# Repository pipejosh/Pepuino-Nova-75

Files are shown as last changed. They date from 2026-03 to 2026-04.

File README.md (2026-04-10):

## Introducing the pepuino75

This is the pepuino75, a 75 percent keyboard, featuring my custom microcontroler, the pepuinoNanoV1 (https://github.com/pipejosh/pepuinoNano-devBoard) althought it is also compatible with a raspberry pi pico!. This keyboard also features a rotary encoder, design to make it as compact as possible, without lossing any of its features!

### Keyboard!

(With 3d printed display)

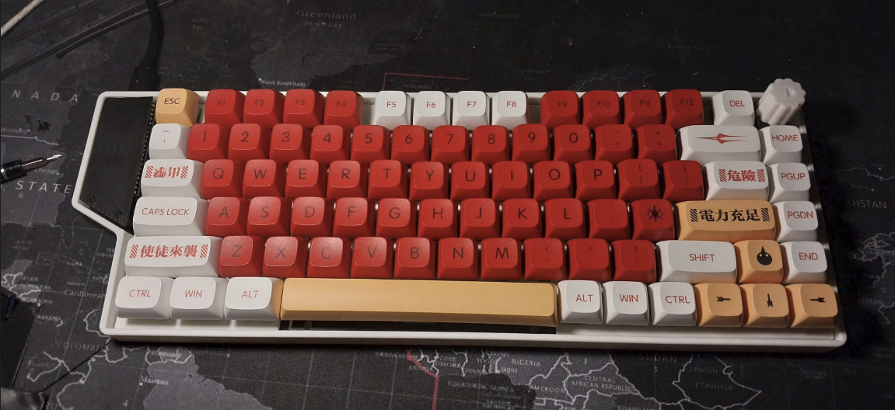
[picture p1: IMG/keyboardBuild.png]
build


(With acrylic display)

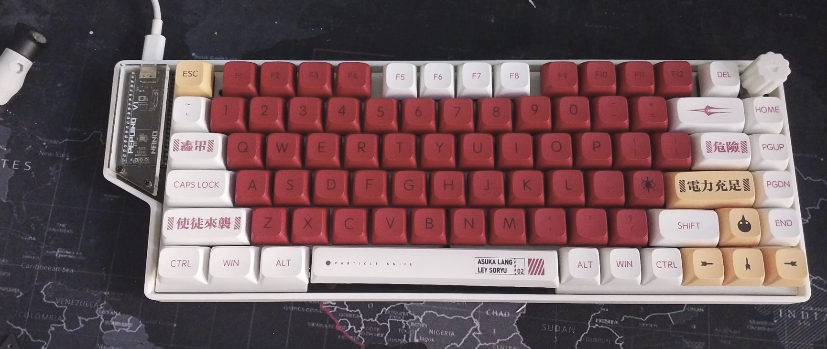
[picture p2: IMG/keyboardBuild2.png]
build


### RENDER
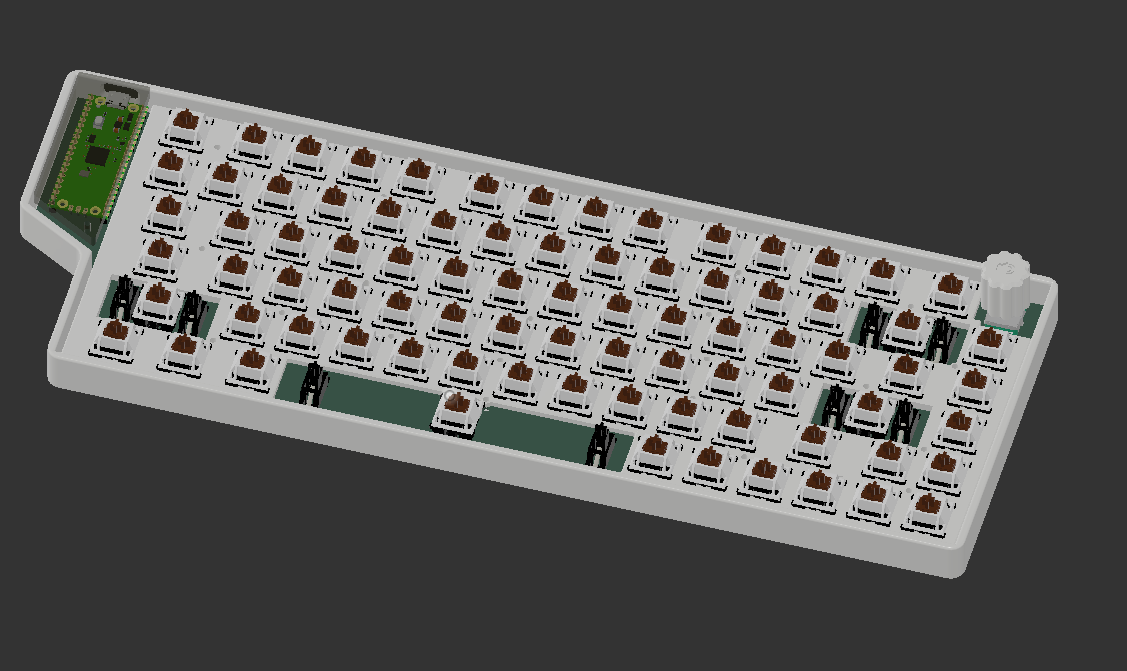
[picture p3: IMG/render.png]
 

### SCHEMATIC
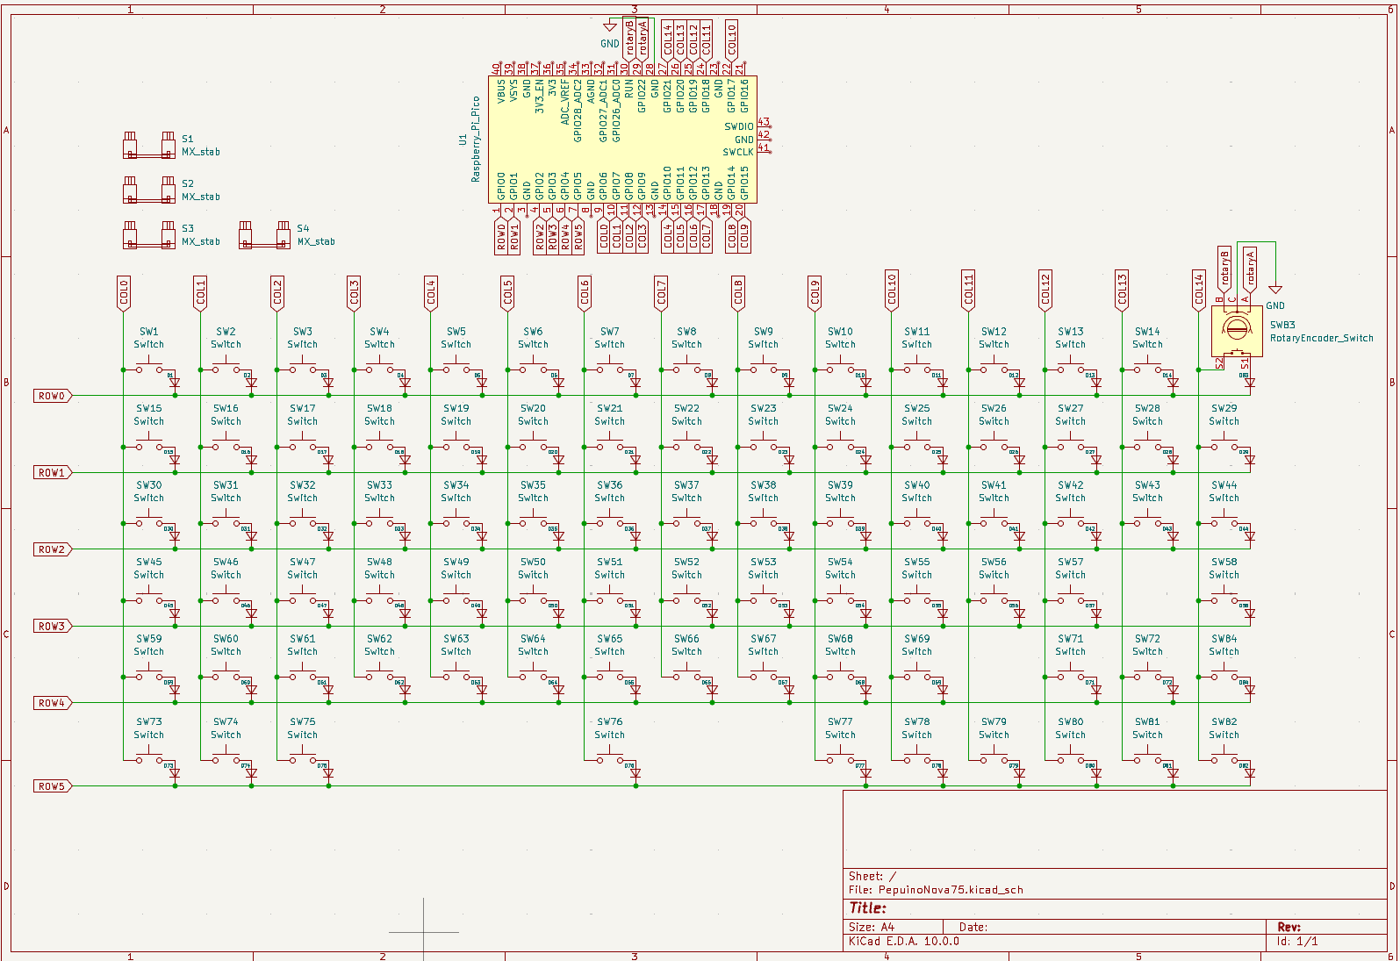
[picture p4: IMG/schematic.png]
schematic
 

### PCB
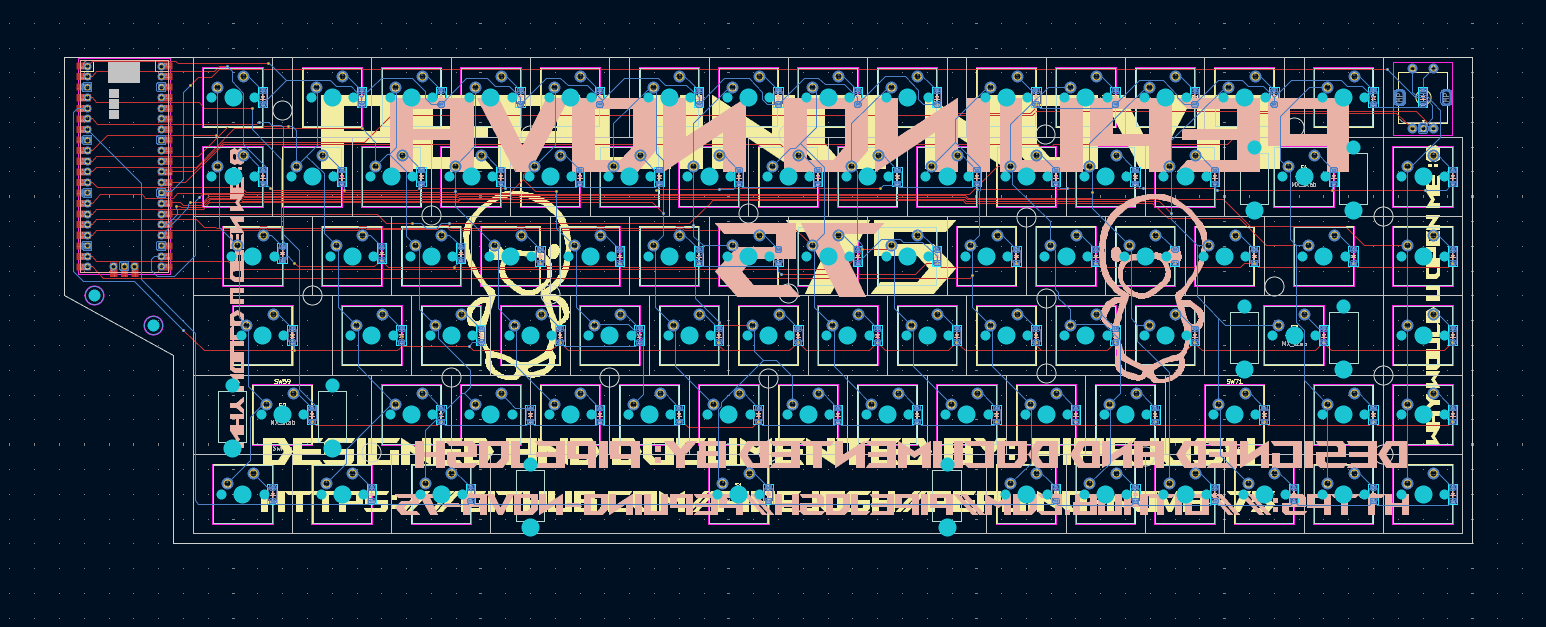
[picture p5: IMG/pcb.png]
 
### CASE
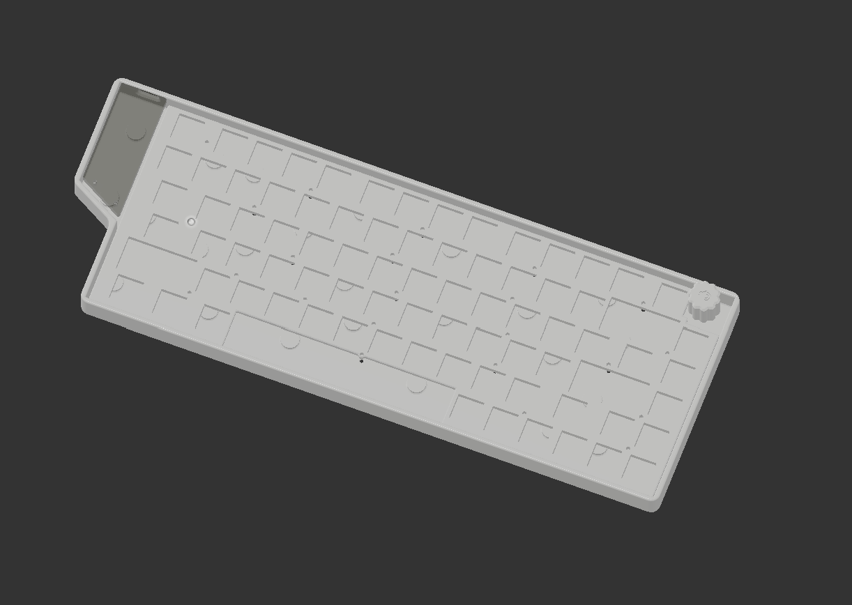
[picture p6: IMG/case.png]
case
 

### BOM
BOM 

### Firmware

This keyboard uses kmk feel free to use the official (https://github.com/KMKfw/kmk_firmware/blob/main/docs/en/Getting_Started.md) documentation in order to flash and install kmk in you microcontroller the firmware folder has the code.py which is what you should copy and paste into your board 

## KIT Components

| Item | Description | Quantity | Unit Price | Total Price | URL |
|---|---|---:|---:|---:|---|
| Keycaps Set | Keycaps for the keyboard | 126 | 0.07 | 8.31 | https://www.aliexpress.com/item/1005007321700850.html |
| Switches | Mechanical switches | 90 | 0.20 | 18.11 | https://www.aliexpress.com/item/1005009787231480.html |
| Diodes | SMD diodes | 100 | 0.03 | 3.15 | https://www.aliexpress.com/item/1005007160563285.html |
| USB-C Cable | USB-C cable | 1 | 3.31 | 3.31 | https://www.aliexpress.com/item/1005005080440661.html |
| M2 Standoff | M2 standoff 5 mm | 50 | 0.05 | 2.50 | https://www.aliexpress.com/item/1005006049595637.html |
| M2 Screw | M2 screw 5 mm | 50 | 0.03 | 1.60 | https://www.aliexpress.com/item/1005005070119421.html |
| Stabilizers | MX stabilizers (6.25u & 2u) | 5 | 0.73 | 3.64 | https://www.aliexpress.com/item/1005007212869086.html |
| Taxes | AliExpress tax | — | — | 4.28 | — |

**KIT Components Subtotal:** 44.90

---

## PCB Costs

| Item | Description | Cost |
|---|---|---:|
| JLCPCB | Pepuino75 PCB | 26.47 |
| JLCPCB Shipping | PCB shipping + taxes | 21.58 |

**PCB Subtotal:** 48.05

---

## GRAND TOTAL

| Category | Amount |
|---|---:|
| KIT Components | 44.90 |
| PCB | 48.05 |
| **TOTAL** | **92.95** |

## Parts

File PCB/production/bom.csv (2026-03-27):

Designator | Footprint | Quantity | Value | LCSC Part #
D1, D10, D11, D12, D13, D14, D15, D16, D17, D18, D19, D2, D20, D21, D22, D23, D24, D25, D26, D27, D28, D29, D3, D30, D31, D32, D33, D34, D35, D36, D37, D38, D39, D4, D40, D41, D42, D43, D44, D45, D46, D47, D48, D49, D5, D50, D51, D52, D53, D54, D55, D56, D57, D58, D59, D6, D60, D61, D62, D63, D64, D65, D66, D67, D68, D69, D7, D71, D72, D73, D74, D75, D76, D77, D78, D79, D8, D80, D81, D82, D83, D84, D9 | Diode_SOD-123 | 83 | ~
S1 | Stabilizer_MX_6.25u | 1 | MX_stab
S2, S3, S4, S5 | Stabilizer_MX_2.00u | 4 | MX_stab
SW1, SW10, SW11, SW12, SW13, SW14, SW15, SW16, SW17, SW18, SW19, SW2, SW20, SW21, SW22, SW23, SW24, SW25, SW26, SW27, SW29, SW3, SW31, SW32, SW33, SW34, SW35, SW36, SW37, SW38, SW39, SW4, SW40, SW41, SW42, SW44, SW46, SW47, SW48, SW49, SW5, SW50, SW51, SW52, SW53, SW54, SW55, SW56, SW58, SW6, SW60, SW61, SW62, SW63, SW64, SW65, SW66, SW67, SW68, SW69, SW7, SW72, SW77, SW78, SW79, SW8, SW80, SW81, SW82, SW84, SW9 | MX_PCB_1.00u | 71 | Switch
SW28 | MX_PCB_2.00u | 1 | Switch
SW30, SW43 | MX_PCB_1.50u | 2 | Switch
SW45, SW71 | MX_PCB_1.75u | 2 | Switch
SW57, SW59 | MX_PCB_2.25u | 2 | Switch
SW73, SW74, SW75 | MX_PCB_1.25u | 3 | Switch
SW76 | MX_PCB_6.25u | 1 | Switch
SW83 | ROT_Alps_EC11E-Switch | 1 | RotaryEncoder_Switch
U1 | Raspberry_Pi_Pico | 1 | Raspberry_Pi_Pico

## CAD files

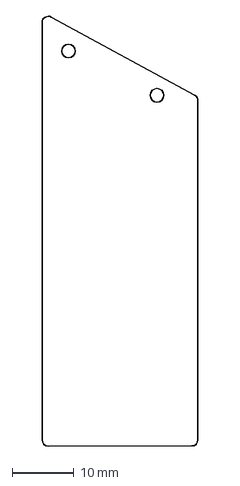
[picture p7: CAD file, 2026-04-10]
CAD/pepuinoNova75Acrylic.dxf
25.2 x 69.5 mm

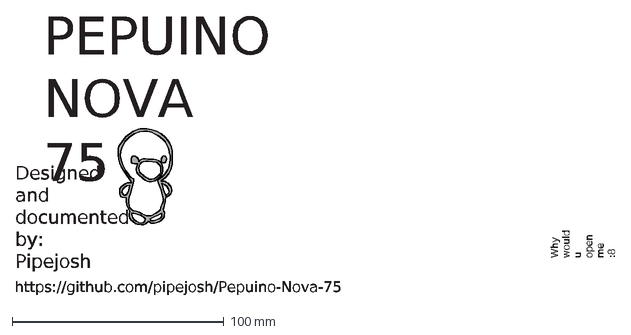
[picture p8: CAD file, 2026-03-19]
PCB/IMG/silkscreenBack.dxf
PEPUINO NOVA
75
Why would u open me :8
Designed and documented by: Pipejosh
https://github.com/pipejosh/Pepuino-Nova-75

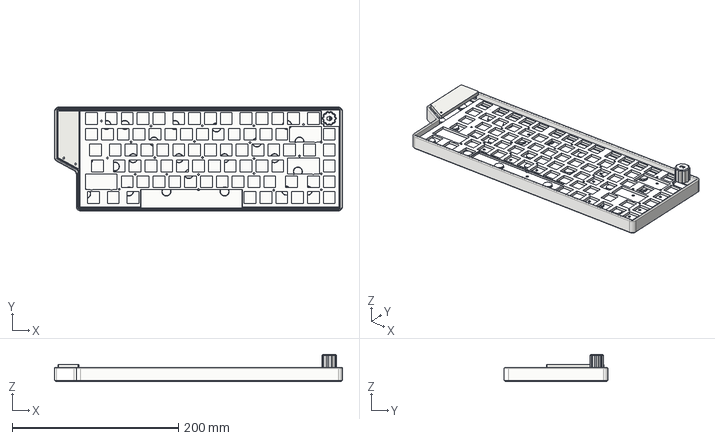
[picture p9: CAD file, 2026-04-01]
CAD/pepuino75CaseSwitchplateEncoder.step
346.1 x 124.7 x 32.6 mm

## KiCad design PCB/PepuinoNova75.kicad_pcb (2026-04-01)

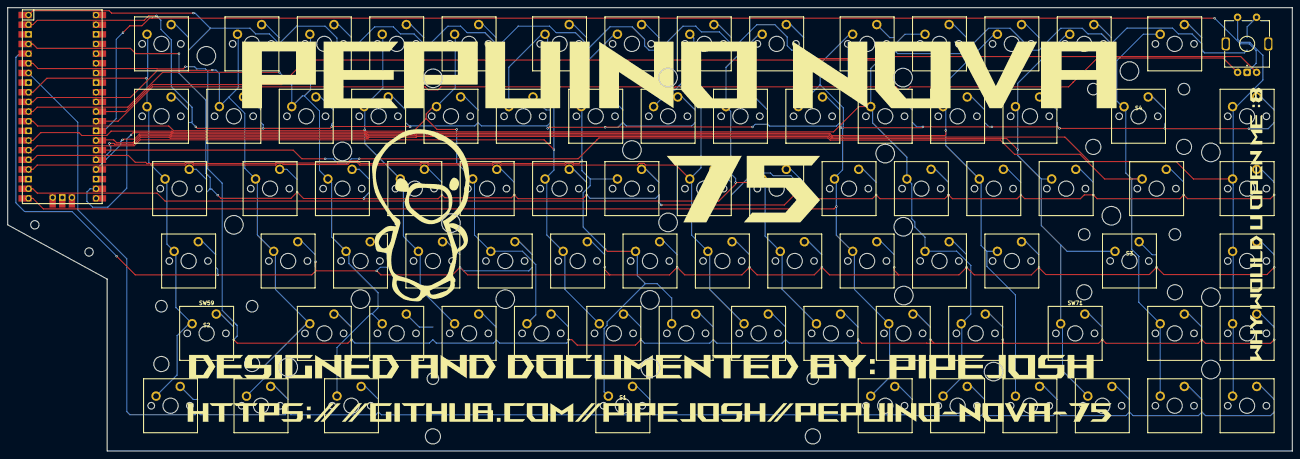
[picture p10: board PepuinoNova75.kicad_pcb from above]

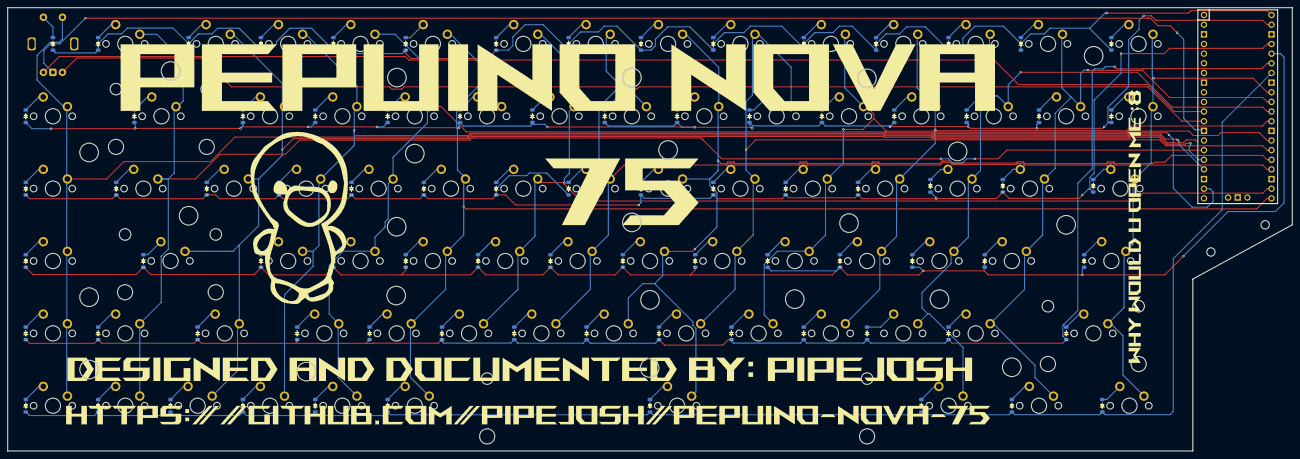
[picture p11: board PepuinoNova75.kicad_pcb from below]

Board: 2 copper layers, 338.1 x 116.7 mm, 173 parts (83 on the bottom side), 107 nets.

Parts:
D1, D2, D3, D4, D5, D6, D7, D8, D9, D10, D11, D12, D13, D14, D15, D16, D17, D18, D19, D20, D21, D22, D23, D24, D25, D26, D27, D28, D29, D30, D31, D32, D33, D34, D35, D36, D37, D38, D39, D40, D41, D42, D43, D44, D45, D46, D47, D48, D49, D50, D51, D52, D53, D54, D55, D56, D57, D58, D59, D60, D61, D62, D63, D64, D65, D66, D67, D68, D69, D71, D72, D73, D74, D75, D76, D77, D78, D79, D80, D81, D82, D83, D84: Diode_SOD-123
H16, H21: MountingHole; MountingHole_2.2mm_M2
S1: MX_stab; Stabilizer_MX_6.25u
S2, S3, S4: MX_stab; Stabilizer_MX_2.00u
SW1, SW2, SW3, SW4, SW5, SW6, SW7, SW8, SW9, SW10, SW11, SW12, SW13, SW14, SW15, SW16, SW17, SW18, SW19, SW20, SW21, SW22, SW23, SW24, SW25, SW26, SW27, SW29, SW31, SW32, SW33, SW34, SW35, SW36, SW37, SW38, SW39, SW40, SW41, SW42, SW44, SW46, SW47, SW48, SW49, SW50, SW51, SW52, SW53, SW54, SW55, SW56, SW58, SW60, SW61, SW62, SW63, SW64, SW65, SW66, SW67, SW68, SW69, SW72, SW77, SW78, SW79, SW80, SW81, SW82, SW84: Switch; MX_PCB_1.00u
SW28: Switch; MX_PCB_2.00u
SW30, SW43: Switch; MX_PCB_1.50u
SW45, SW71: Switch; MX_PCB_1.75u
SW57, SW59: Switch; MX_PCB_2.25u
SW73, SW74, SW75: Switch; MX_PCB_1.25u
SW76: Switch; MX_PCB_6.25u
SW83: RotaryEncoder_Switch; ROT_Alps_EC11E-Switch
U1: Raspberry_Pi_Pico

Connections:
COL0: SW1.1, SW15.1, SW30.1, SW45.1, SW59.1, SW73.1, U1.9 (GPIO6)
COL1: SW2.1, SW16.1, SW31.1, SW46.1, SW60.1, SW74.1, U1.10 (GPIO7)
COL2: SW3.1, SW17.1, SW32.1, SW47.1, SW61.1, SW75.1, U1.11 (GPIO8)
COL3: SW4.1, SW18.1, SW33.1, SW48.1, SW62.1, U1.12 (GPIO9)
COL4: SW5.1, SW19.1, SW34.1, SW49.1, SW63.1, U1.14 (GPIO10)
COL5: SW6.1, SW20.1, SW35.1, SW50.1, SW64.1, U1.15 (GPIO11)
COL6: SW7.1, SW21.1, SW36.1, SW51.1, SW65.1, SW76.1, U1.16 (GPIO12)
COL7: SW8.1, SW22.1, SW37.1, SW52.1, SW66.1, U1.17 (GPIO13)
COL8: SW9.1, SW23.1, SW38.1, SW53.1, SW67.1, U1.19 (GPIO14)
COL9: SW10.1, SW24.1, SW39.1, SW54.1, SW68.1, SW77.1, U1.20 (GPIO15)
COL10: SW11.1, SW25.1, SW40.1, SW55.1, SW69.1, SW78.1, U1.22 (GPIO17)
COL11: SW12.1, SW26.1, SW41.1, SW56.1, SW79.1, U1.24 (GPIO18)
COL12: SW13.1, SW27.1, SW42.1, SW57.1, SW71.1, SW80.1, U1.25 (GPIO19)
COL13: SW14.1, SW28.1, SW43.1, SW72.1, SW81.1, U1.26 (GPIO20)
COL14: SW29.1, SW44.1, SW58.1, SW82.1, SW83.S2, SW84.1, U1.27 (GPIO21)
GND: SW83.C, U1.28 (GND)
unnamed: D1.2 (A), SW1.2
unnamed: D2.2 (A), SW2.2
unnamed: D3.2 (A), SW3.2
unnamed: D4.2 (A), SW4.2
unnamed: D5.2 (A), SW5.2
unnamed: D6.2 (A), SW6.2
unnamed: D7.2 (A), SW7.2
unnamed: D8.2 (A), SW8.2
unnamed: D9.2 (A), SW9.2
unnamed: D10.2 (A), SW10.2
unnamed: D11.2 (A), SW11.2
unnamed: D12.2 (A), SW12.2
unnamed: D13.2 (A), SW13.2
unnamed: D14.2 (A), SW14.2
unnamed: D15.2 (A), SW15.2
unnamed: D16.2 (A), SW16.2
unnamed: D17.2 (A), SW17.2
unnamed: D18.2 (A), SW18.2
unnamed: D19.2 (A), SW19.2
unnamed: D20.2 (A), SW20.2
unnamed: D21.2 (A), SW21.2
unnamed: D22.2 (A), SW22.2
unnamed: D23.2 (A), SW23.2
unnamed: D24.2 (A), SW24.2
unnamed: D25.2 (A), SW25.2
unnamed: D26.2 (A), SW26.2
unnamed: D27.2 (A), SW27.2
unnamed: D28.2 (A), SW28.2
unnamed: D29.2 (A), SW29.2
unnamed: D30.2 (A), SW30.2
unnamed: D31.2 (A), SW31.2
unnamed: D32.2 (A), SW32.2
unnamed: D33.2 (A), SW33.2
unnamed: D34.2 (A), SW34.2
unnamed: D35.2 (A), SW35.2
unnamed: D36.2 (A), SW36.2
unnamed: D37.2 (A), SW37.2
unnamed: D38.2 (A), SW38.2
unnamed: D39.2 (A), SW39.2
unnamed: D40.2 (A), SW40.2
unnamed: D41.2 (A), SW41.2
unnamed: D42.2 (A), SW42.2
unnamed: D43.2 (A), SW43.2
unnamed: D44.2 (A), SW44.2
unnamed: D45.2 (A), SW45.2
unnamed: D46.2 (A), SW46.2
unnamed: D47.2 (A), SW47.2
unnamed: D48.2 (A), SW48.2
unnamed: D49.2 (A), SW49.2
unnamed: D50.2 (A), SW50.2
unnamed: D51.2 (A), SW51.2
unnamed: D52.2 (A), SW52.2
unnamed: D53.2 (A), SW53.2
unnamed: D54.2 (A), SW54.2
unnamed: D55.2 (A), SW55.2
unnamed: D56.2 (A), SW56.2
unnamed: D57.2 (A), SW57.2
unnamed: D58.2 (A), SW58.2
unnamed: D59.2 (A), SW59.2
unnamed: D60.2 (A), SW60.2
unnamed: D61.2 (A), SW61.2
unnamed: D62.2 (A), SW62.2
unnamed: D63.2 (A), SW63.2
unnamed: D64.2 (A), SW64.2
unnamed: D65.2 (A), SW65.2
unnamed: D66.2 (A), SW66.2
unnamed: D67.2 (A), SW67.2
unnamed: D68.2 (A), SW68.2
unnamed: D69.2 (A), SW69.2
unnamed: D71.2 (A), SW71.2
unnamed: D72.2 (A), SW72.2
unnamed: D73.2 (A), SW73.2
unnamed: D74.2 (A), SW74.2
unnamed: D75.2 (A), SW75.2
unnamed: D76.2 (A), SW76.2
unnamed: D77.2 (A), SW77.2
unnamed: D78.2 (A), SW78.2
unnamed: D79.2 (A), SW79.2
unnamed: D80.2 (A), SW80.2
unnamed: D81.2 (A), SW81.2
unnamed: D82.2 (A), SW82.2
unnamed: D83.2 (A), SW83.S1
unnamed: D84.2 (A), SW84.2
ROW0: D1.1 (K), D2.1 (K), D3.1 (K), D4.1 (K), D5.1 (K), D6.1 (K), D7.1 (K), D8.1 (K), D9.1 (K), D10.1 (K), D11.1 (K), D12.1 (K), D13.1 (K), D14.1 (K), D83.1 (K), U1.1 (GPIO0)
ROW1: D15.1 (K), D16.1 (K), D17.1 (K), D18.1 (K), D19.1 (K), D20.1 (K), D21.1 (K), D22.1 (K), D23.1 (K), D24.1 (K), D25.1 (K), D26.1 (K), D27.1 (K), D28.1 (K), D29.1 (K), U1.2 (GPIO1)
ROW2: D30.1 (K), D31.1 (K), D32.1 (K), D33.1 (K), D34.1 (K), D35.1 (K), D36.1 (K), D37.1 (K), D38.1 (K), D39.1 (K), D40.1 (K), D41.1 (K), D42.1 (K), D43.1 (K), D44.1 (K), U1.4 (GPIO2)
ROW3: D45.1 (K), D46.1 (K), D47.1 (K), D48.1 (K), D49.1 (K), D50.1 (K), D51.1 (K), D52.1 (K), D53.1 (K), D54.1 (K), D55.1 (K), D56.1 (K), D57.1 (K), D58.1 (K), U1.5 (GPIO3)
ROW4: D59.1 (K), D60.1 (K), D61.1 (K), D62.1 (K), D63.1 (K), D64.1 (K), D65.1 (K), D66.1 (K), D67.1 (K), D68.1 (K), D69.1 (K), D71.1 (K), D72.1 (K), D84.1 (K), U1.6 (GPIO4)
ROW5: D73.1 (K), D74.1 (K), D75.1 (K), D76.1 (K), D77.1 (K), D78.1 (K), D79.1 (K), D80.1 (K), D81.1 (K), D82.1 (K), U1.7 (GPIO5)
rotaryA: SW83.A, U1.29 (GPIO22)
rotaryB: SW83.B, U1.30 (RUN)

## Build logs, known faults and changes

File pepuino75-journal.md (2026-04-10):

<!--
  This journal is auto generated by Hack Club Blueprint.
-->

# 1/3/2026 - Create the shematic diagram  

_Time spent: 3.0h_  

after thinking what can i do with the custom devboard i just made (the pepuinoNanoV1) the thought where focused towards a keybaord, so i got hand on kicad and started making the schematic diagram for the pepuino75 (75 cuz its a 75 percent keybaord)



# NOTE

the pins in this schematic diagram might seen like wrong but i changed the pinout in the devboard, so i just made it match

pinout of the pepuinoNanoV1


# 1/4/2026 - Routed the board  

_Time spent: 4.0h_  

today i routed the pcb, and after all the pain of the other projects (the dev board, launchpad) this felt like a breze, it didnt take me as long as i expected, plus i fixed an error in which i forgot to connect the gnd from the roatry encoder with the gnd in the pepuinoNanoV1 



# 1/5/2026 5:19 PM - Re route the pcb + fix minor issues  

_Time spent: 4.0h_  

sou i noticed that the last layer of the keyboard was completely alligned with the previous layer of the keyboard, and after a solid time, i figured, somehow i had one more extra key that was messing everything up, and after deleting it, the fit was perfect, therefore i had to route the pcb again, which wasnt so much of a problem + i added the stabilizers and the spacers place for the pcb!

new pcb!



# 1/5/2026 5:37 PM - design the case   

_Time spent: 4.0h_  

after the pcb was basically done, i decided to export the step and move it to fusion, and around it, model the case for the new keyboarad, im planning printing this on the h2d, so size is not an issue while printing this case



# 1/13/2026 - Update the case of the pepuino 75 + add firmware  

_Time spent: 4.0h_  

todays work was to update the case of the keyboard, this includes, adding a switchplate for the swtiches, plus add the knob for the rotary encoder, plus added some nice fillets and chamfers, overall im very happy with how this new case turned out! 

in the firmware topic, i decided to use QMK since it is a reliable option that in fact supports the rapsberry pi pico chip, even thought i havent test the firmaware yet, im happy overall with the new layout for the keyboard, just a basic 75 generic keyboard.

Image of the case 
case

New render of this case 
render

Tentative image of the layout



# 3/22/2026 - Fix crucial mistakes in the case  

_Time spent: 1.0h_  

before sending it to the H2D I wanted to make sure no error happened and theres when i noticed that the wire for the stabilizers where gonna collide with the case so after some tweaking I fixed that and I also added the acrylic display I will cut it uses 8 mm standoffs



# 3/23/2026 - Soder all the diodes!  

_Time spent: 4.0h_  

After A LOT of waiting all the components arrived, and now it was time to soder almost 100 diodes WHICH HOLY TOOK so much time although it was time well spended 

btwww the pcb turned out REAALY REALLY nicely and the silkscreen IS PRISTINEEE i love it so much

now im going to upload the firmware I decided to use kmk since I'm using a rp2040 board so hopefully it's not that bad! I'm also printing the swithcplate in the school H2D and it barely fitted.



# 3/24/2026 - Print the switchplate and re write the firmware (PAINFULL)  

_Time spent: 5.0h_  

Sooooo the H2D has an insane quality and since its bigger it had no problems to print this. After testing the tolerances for the switches I can gladly say IT FITS PERFECTLY!



and while I swapped all the switches I also decided to write the firmware for the keb again. I decided to use KMK because the pepuino nano uses a rp2040 microcontroller which runs python natively. After some research and READING THE DOCUMENTATION. I started writing the firmware, and it was sooooooo nice, I was at a flow state just writing the code and making sure everything is nice reading the documentation and typing it out and after some hours the firware is ready! Still untested since I want to soder the switches to test it first!



# 3/25/2026 - Soder all the swtiches + IRL DEBUGGING + Assemble  

_Time spent: 6.5h_  

The day has finally arrived both the case and the switchplate has benn printed out, and after doing a test assemble the keb was looking great. Now it is time to soder all 82 keys since each switch has 2 legs I sodered in total 164 legs which took me a whileee.



Once all the legs where sodered it was finally time to properly test the firmware and see if every key works (it didnt) 2 keys didnt work the space and the pg down, the first one was because i forgot to soder the other leg of the diode and the ohter one was because of a crucial mistakes i've done turns out have shorted the switch 
 so it didnt work the fix was to grab a utility knife and cut the trace manually. Although it took me a bit it was not as hard as I thought. 


The other issue I encountered was more of a pain in the a** the encoder wasnt working the switch of the encoder worked so that mean the physical encoder worked, the pins of the pepuinoNano worked, so it wasnt the microcontroller and turns out that the gnd in the encoder was connected to the vcc of the microcontroller! So I needed to brake the traces a again with the utility knife and I needed to hard soder a wire in the back 


Although it was challenging at the end I had a working keyboard that I've done myself which I am really proud of, doing something from scratch and seeing it how it evolves is such an amazing experience!



# 3/26/2026 - Assemble the keb! Finished it!  

_Time spent: 4.0h_  

Final day! today the was the last day I speneded all assemblying and putting some keycaps on be build tured out great! and after some taping and sodering some loose switches the keyboard is ready to use! 

Featuring silent green swtiches for schoolwork at mightnight, custom made microcontroller and a rotary encoder.



# 3/31/2026 - More debugginn + fix encoder firware  (KEB DONEEEEEEEEEEEEE)  

_Time spent: 2.5h_  

Now the encoder features volume up and volume down after looking at the documentation and suffering with this same documentation I noticed I was lacking a set a braces and thats why the encoder didnt work so after fixing that I moved to the next issue



The up arrow didnt work and after looking at the firware first I noticed there was nothing wrong with this, so I opened the keyboard up and after looking at the diodes nothing seemed wrong with this and after taking a look at the schematic the problem was as clear as water (i didnt connect the switch to the matrix) so I ran another wire and soder it to another switch and just like magic it worked flawesly nowwwwwww I can say its DONEEEEE



# 4/9/2026 - Cut thee acrylic piece for the display + update repo!  

_Time spent: 1.5h_  

Even so the keb was done, I still wanted it to look likee the acrylic pieces the corne has. So I exported the sketch of the part in fusion as a dxf, load it into illustrator, put it in a usb stick, open it in retina engrave and cutted the part



Cutting the acrylic was fun! although it started to light on fire since the protective film of the acrylic was still on 



(And the proteective film got a bit burned too hehe)



And now you can choose your own adventures as my chemistry teacher says, either 3d print that piece for a NOT CLEAR orrrrrrrr lase cut the piece of acrylic using the dxf attached, the file is in mm just in case anyone strugles with the scales

Note: Nowwwww I can finally seee the beautiful silkscreen of the pepuino nano v1

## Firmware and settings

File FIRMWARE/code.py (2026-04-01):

print("Starting")
print("Impboard")

import board

from kmk.kmk_keyboard import KMKKeyboard
from kmk.keys import KC
from kmk.scanners import DiodeOrientation
from kmk.modules.encoder import EncoderHandler
from kmk.extensions.media_keys import MediaKeys


encoder = EncoderHandler()
keyboard = KMKKeyboard()

keyboard.modules.append(MediaKeys())
keyboard.modules.append(encoder)

encoder.pins = ((board.GP21, board.GP22, None),)
keyboard.col_pins = (board.GP6, board.GP7, board.GP8, board.GP9, board.GP10, board.GP11, board.GP12, board.GP13, board.GP14, board.GP15, board.GP16, board.GP17, board.GP18, board.GP19, board.GP20)
keyboard.row_pins = (board.GP0, board.GP1, board.GP2, board.GP3, board.GP4, board.GP5)
keyboard.diode_orientation = DiodeOrientation.COL2ROW

keyboard.keymap = [

    [ KC.ESC, KC.F1, KC.F2, KC.F3, KC.F4, KC.F5, KC.F6, KC.F7, KC.F8, KC.F9, KC.F10, KC.F11, KC.F12, KC.DEL, KC.MPLY, 
      KC.GRV, KC.N1, KC.N2, KC.N3, KC.N4, KC.N5, KC.N6, KC.N7, KC.N8, KC.N9, KC.N0, KC.MINS, KC.EQL, KC.BSPC, KC.HOME, 
      KC.TAB, KC.Q, KC.W, KC.E, KC.R, KC.T, KC.Y, KC.U, KC.I, KC.O, KC.P, KC.LBRC, KC.RBRC, KC.BSLS, KC.PGUP, 
      KC.ESC, KC.A, KC.S, KC.D, KC.F, KC.G, KC.H, KC.J, KC.K, KC.L, KC.SCLN, KC.QUOT, KC.ENT, KC.NO, KC.PGDN,    
      KC.LSFT, KC.Z, KC.X, KC.C, KC.V, KC.B, KC.N, KC.M, KC.COMM, KC.DOT, KC.SLASH, KC.NO, KC.RSFT, KC.UP, KC.END,
      KC.LCTRL, KC.LWIN, KC.LALT, KC.NO, KC.NO, KC.NO, KC.SPACE, KC.NO, KC.NO, KC.RALT, KC.RWIN, KC.RCTRL, KC.LEFT, KC.DOWN, KC.RIGHT]
    
]

encoder.map= [ ((KC.VOLU, KC.VOLD), )]






if __name__ == '__main__':
    keyboard.go()

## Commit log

2026-03-19 update images and add silkscreen pcb
    [designators.csv, pepuino75.kicad_pcb, silkscreenBack.dxf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]
2026-03-27 Update CAD files
    [pepuino75CaseSwitchplateEncoder.step]
2026-03-27 update pcb and fix crucial mistakes
    [PepuinoNova75.kicad_pcb, PepuinoNova75.kicad_sch, bom.csv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]
2026-04-01 fix fatal error in pcb + fix case + update images
    [PepuinoNova75.kicad_pcb, PepuinoNova75.kicad_sch, pepuino75CaseSwitchplateEncoder.step]
2026-04-01 update rotary encoder firmware
2026-04-10 add the acrylic piece dxf (in mm)
    [pepuinoNova75Acrylic.dxf]
